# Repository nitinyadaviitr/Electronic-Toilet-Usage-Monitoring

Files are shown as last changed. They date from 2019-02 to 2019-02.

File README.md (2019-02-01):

# Electronic-Toilet-Usage-Monitoring
For accelerating the effectiveness of Swachh Bharat Abhiyaan, the monitoring of the goals under Swachh Bharat Abhiyaan is the most important thing to be done.
To successfully implement the cause of the Millions of toilets made under Swachh Bharat Abhiyaan, having a record of how much they are actually being used is important.
For monitoring toilet usage in the rural areas of India, we have developed ETUM. 
ETUM has been made considering conditions like lack of electricity in villages, remoteness of the area and lack of services.
ETUM is a cost effective device which will tell the approximate usage of the toilets for a duration of about 5 months after which the data will have to be recorded manually.

General Description:-
ETUM operates on the principle of human detection technology using a PIR sensor. A PIR sensor detects Infrared rays emitted by the human body.
Everytime a person enters into the toilet, the PIR sensor will read high increasing the previous value by 1, and will store this data for about 5 months with average usage in every week during these
months.
Our idea suggests that the device will be installed in every toilet present into the village and after a duration of 5 months a person has to go to every house and take
the reading of the device and replace the battery used in it. Then he will give the feedback to a centralised database where the data of all the villages will be recorded and studied.
The device is accurate as whole device works without manual work (except manual recording) and has a long lifetime if not damaged physically.

Cost-effectiveness:-
Calculating the whole manufacturing of the device along with the price of each and every component used in it, the device will have an estimated cost of 150 rupees.
The exact cost of the device depends on the amount of quantities being ordered collectively and from where they are being ordered and many other factors.
(The price data of products we have considered for evaluation of cost of our device have been provided in the PDF attached)

Scalability:-
The device is safe to use and have an optimum cost for a large scale usage in rural or urban areas.
The device has no maintenance cost and low operating cost.
Also assigning the responsibility of data recording from every house in the village to a person is feasible and would help to keep an accurate record of the whole data.
Extremely low maintenance cost, long lifetime and low cost of the device makes it perfect for large scale usage.

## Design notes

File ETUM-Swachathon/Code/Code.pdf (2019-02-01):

/*
* main.c
*
* Created on: 25-Aug-2017
* Author: utkarsh
*/

#define F_CPU 8000000UL

#define LCD_PRT PORTA

#define LCD_DDR DDRA

#define LCD_PIN PINA

#define LCD_RS 3

#define LCD_EN 2

#define LCD_RW 1

#include <avr/io.h>

#include <util/delay.h>

#include <stdlib.h>

#include <avr/interrupt.h>

volatile unsigned int counter=0; | //Counter for Timer/Counter1
int day=0; | //Number of days passed
unsigned int month[6]; | //Array of monthly usage data
char month_no=0;
int count=0; | //PIR Count of people

void delay_us(int d)
{
_delay_us(d)
}

void delay_ms(int d)
{
_delay_ms(d)
}

// Functions of Timer/Counter1
ISR(TIM1_OVF) | //Timer/Counter1 Overflow ISR
{
counter++; | //+2 sec
TCNT1H=0xC2; | // Adding offset
TCNT1L=0xF5;
}
void initT1() | //Initialization of Timer/Counter1
{
TCNT1H=0xC2; | // Adding offset
TCNT1L=0xF5;
TCCR1A=0x00; | //Normal Mode
TCCR1B=0x05; | //prescaler of 1024

TIMSK1 |= 1<<TOIE1; | //enable Timer/Counter1 overflow interrupt
}

//Function of Pir Sensor
ISR(INT0)
{
count++;
GIMSK = 0x00; | //Disable External Interrupt Request
delay_ms(120000); | //Delay of 2 min
GIMSK =(1<<INT0)|(0<<PCIE1)|(0<<PCIE0); | //External Interrupt Request 0
//Enable and Pin Change Interrupt //Disable for 1 and 0
}
void initI0() | //Initialization Of External Interrupt 0
{
GIMSK =(1<<INT0)|(0<<PCIE1)|(0<<PCIE0); | //External Interrupt Request 0
//Enable and Pin Change Interrupt //Disable for 1 and 0
MCUCR = (1<<ISC01)|(1<<ISC00); | //The rising edge of INT0 generates
//an interrupt request
}

//LCD
void lcdCommand( unsigned char cmnd )
{
LCD_PRT = (LCD_PRT & 0x0F) | (cmnd & 0xF0);
LCD_PRT &= ~ (1<<LCD_RS); | //RS = 0 for command
LCD_PRT &= ~ (1<<LCD_RW); | //RW = 0 for write
LCD_PRT |= (1<<LCD_EN); | //EN = 1 for H-to-L pulse
delay_us(1); | //make EN pulse wider
LCD_PRT &= ~ (1<<LCD_EN); | //EN = 0 for H-to-L pulse
delay_us(20); | //wait
LCD_PRT = (LCD_PRT & 0x0F)|(cmnd<<4); | //Send low nibble to D4-D7
LCD_PRT |= (1<<LCD_EN); | //EN = 1 for H-to-L pulse
delay_us(1); | //make EN pulse wider
LCD_PRT &= ~ (1<<LCD_EN); | //EN = 0 for H-to-L pulse
}

void lcdData( unsigned char data )
{
LCD_PRT = (LCD_PRT & 0x0F) | (data & 0xF0); | //Send high nibble to D4-D7
LCD_PRT |= (1<<LCD_RS); | //RS = 1 for data
LCD_PRT &= ~ (1<<LCD_RW); | //RW = 0 for write
LCD_PRT |= (1<<LCD_EN); | //EN = 1 for H-to-L pulse
delay_us(1); | //make EN pulse wider
LCD_PRT &= ~ (1<<LCD_EN); | //EN = 0 for H-to-L pulse
LCD_PRT = (LCD_PRT & 0x0F) | (data <<4); | //Send low nibble to D4-D7

LCD_PRT |= (1<<LCD_EN); | //EN = 1 for H-to-L pulse
delay_us(1); | //make EN pulse wider
LCD_PRT &= ~ (1<<LCD_EN); | //EN = 0 for H-to-L pulse
}

void lcd_init()
{
LCD_DDR = 0x7F;
LCD_PRT &=~(1<<LCD_EN); | //LCD_EN = 0
delay_us(2000);
lcdCommand(0x33); | //send $33 for init.
delay_us(100);
lcdCommand(0x32); | //send $32 for init
delay_us(100);
lcdCommand(0x28); | //init. LCD 2 line,5*7 matrix
delay_us(100);
lcdCommand(0x0e); | //display on, cursor on
delay_us(100);
lcdCommand(0x01); | //clear LCD
delay_us(2000);
lcdCommand(0x06); | //Shift cursor right
delay_us(100);
}
void lcd_gotoxy(unsigned char x, unsigned char y) | //function to goto x,y on LCD
{
unsigned char firstCharAdr[]={0x80,0xC0,0x94,0xD4} ; lcdCommand(firstCharAdr[y-1] + x - 1);
delay_us(100);
}
void lcd_print(char * str ) | //function to print given str. on LCD
{
unsigned char i = 0 ;
while(str[i]!=0)
{
lcdData(str[i]);
i++ ;
}
}

//Main Code
int main(void)
{
DDRA=0b00111111; | //LCD Interfacing
PORTB2=1; | //pull up activated
initI0(); | //External Interrupt 0
initT1(); | //Timer/Counter1 to count time

sei(); | //enable global interrupt
while(1)
{
if(counter>=43200) | //No of days passed (30*60*24 = 43200 )
{
day++; | //+day
counter=counter-43200; | //counter remainder
}
if (day==30)
{
month[month_no]=((count/2)/30); | //Assigning monthly average data
month_no++; | //+month_no
day=0;
}
}

if ( PINA & 0b00000001)
{
//LCD code
lcd_init();
lcd_gotoxy(1,1);
lcd_print(“%4d %4d %4d”,month[0], month[1], month[2]); lcd_gotoxy(1,2);
lcd_print(“%4d %4d %4d”,month[3], month[4], month[5]);

}

}

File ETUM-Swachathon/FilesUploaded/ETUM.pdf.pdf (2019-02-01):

# ETUM

ELECTRONIC TOILET USAGE MONITORING

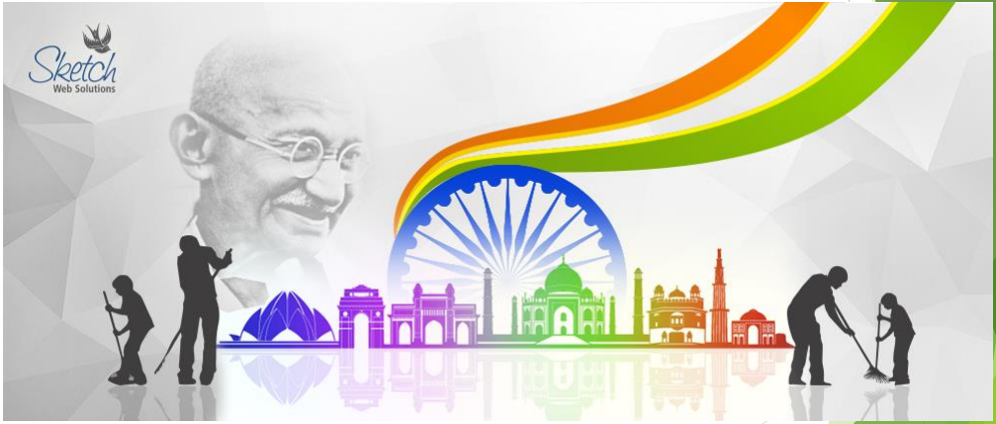
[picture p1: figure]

# ETUM

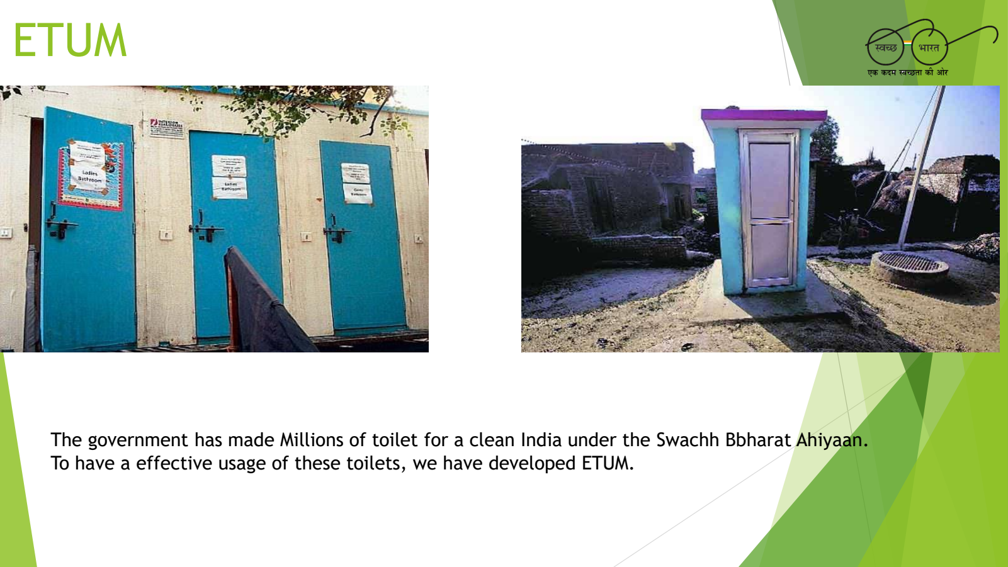
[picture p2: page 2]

The government has made Millions of toilet for a clean India under the Swachh Bbharat Ahiyaan. To have a effective usage of these toilets, we have developed ETUM.

# ETUM WORKING`

# ETUM

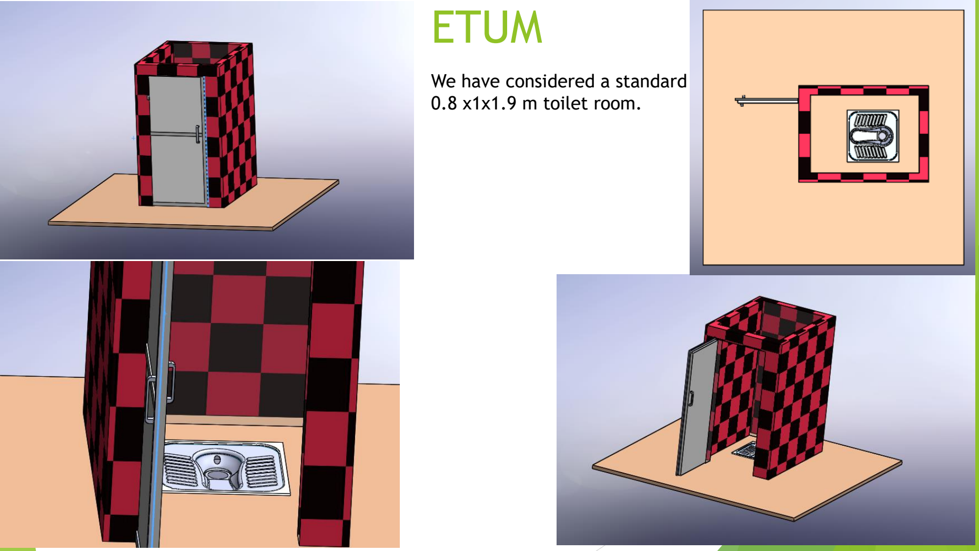
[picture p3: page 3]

We have considered a standard 0.8 x1x1.9 m toilet room.

# PIR SENSOR

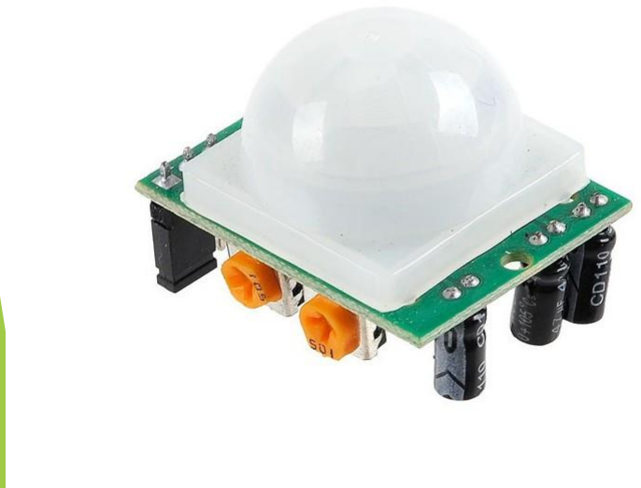
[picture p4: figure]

PIR sensors allow you to sense motion, almost always used to detect whether a human has moved in or out of the sensors range. They are small, inexpensive, lowpower, easy to use and don't wear out. For that reason they are commonly found in appliances and gadgets used in homes or businesses. They are often referred to as PIR, "Passive Infrared", "Pyroelectric", or "IR motion" sensors.

# ETUM

# PIR SENSOR

PIRs are basically made of a pyroelectric sensor (which you can see above as the round (http://en.wikipedia.org/wiki/Pyroelectric) metal can with a rectangular crystal in the center), which can detect levels of infrared radiation. Everything emits some low level radiation, and the hotter something is, the more radiation is emitted. The sensor in a motion detector is actually split in two halves. The reason for that is that we are looking to detect motion (change) not average IR levels. The two halves are wired up so that they cancel each other out. If one half sees more or less IR radiation than the other, the output will swing high or low.

# ETUM

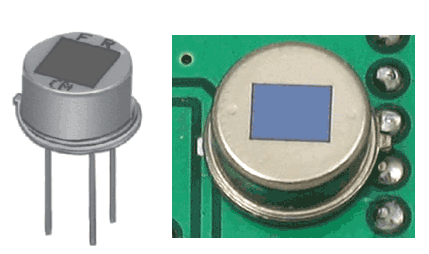
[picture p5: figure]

# PIR SENSOR WORKING

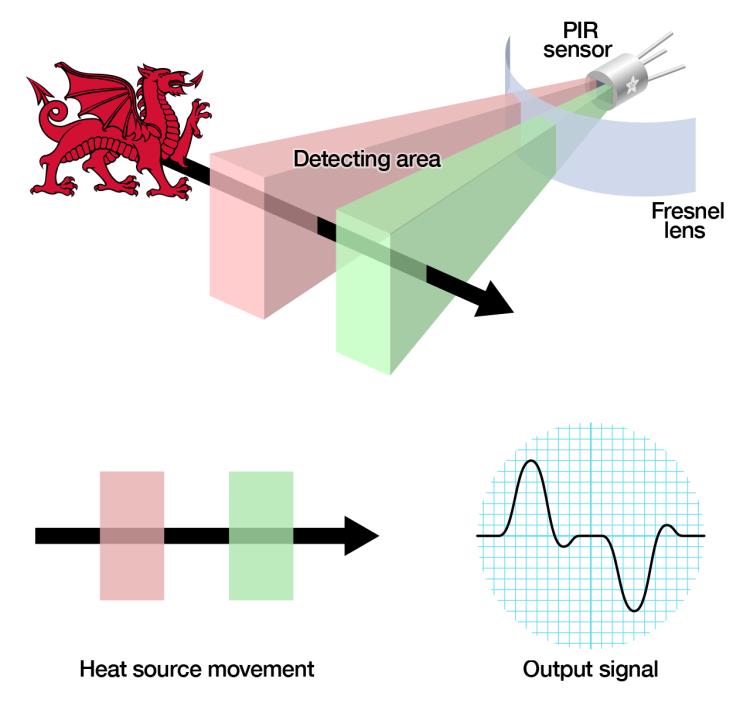
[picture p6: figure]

The PIR sensor itself has two slots in it, each slot is made of a special material that is sensitive to IR. When the sensor is idle, both slots detect the same amount of IR, the ambient amount radiated from the room or walls or outdoors. When a warm body like a human or animal passes by, it first intercepts one half of the PIR sensor, which causes a positive differential change between the two halves. When the warm body leaves the sensing area, the reverse happens, whereby the sensor generates a negative differential change. These change pulses are what is detected.

# ETUM

# ETUM WORKING

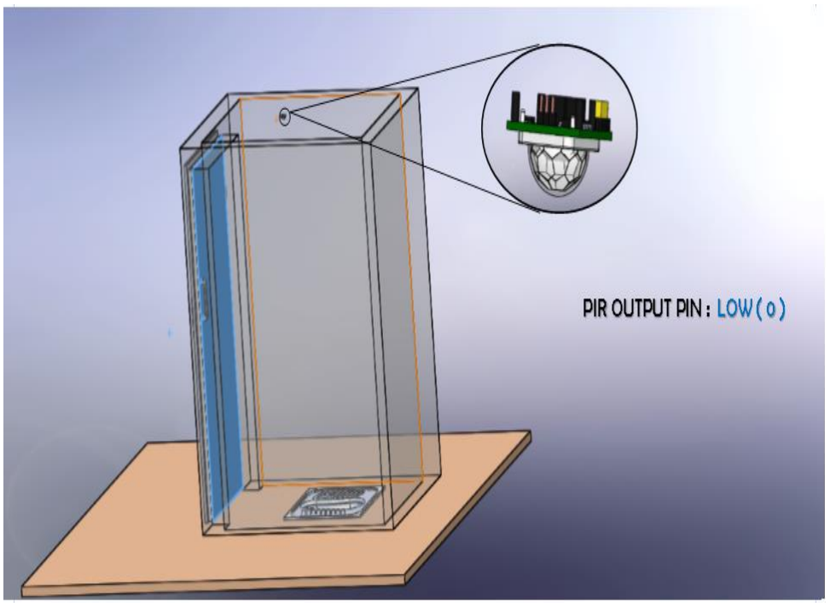
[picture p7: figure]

When the toilet is not being used, the sensor reads low.

# ETUM WORKING

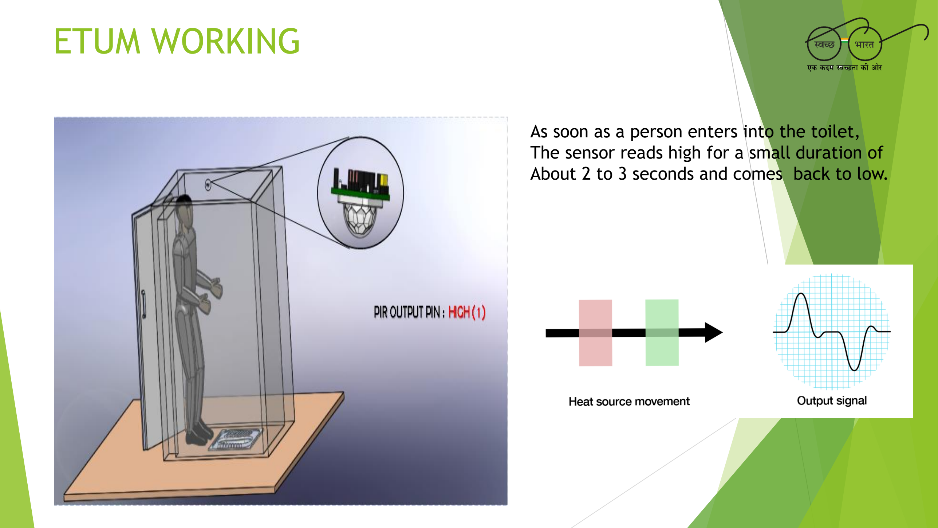
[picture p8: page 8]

As soon as a person enters into the toilet, The sensor reads high for a small duration of About 2 to 3 seconds and comes back to low.

# ETUM IDEA

The device works on the principle of infrared rays detection by a PIR sensor. The device is designed to work continuously for about 5 months without any maintenance in between.
After duration of these 5 months, a person will have to record the data that Is stored in these 5 months by plugging in an LCD screen into the LCD pins Provided in ETUM.

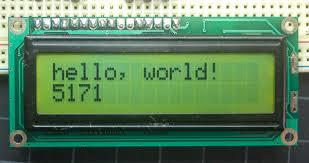
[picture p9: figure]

A Standard 16x2 LCD screen.

# ETUM IDEA

We instead of using a standard HC-SR501, have designed our own PCB module removing the unnecessary voltage Regulator and potentiometer for minimum power dissipation. We in the PCB we have added a microcontroller(ATTINY 24A) for the processing of the data along with separate pins in which the LCD has to be Plugged-in to read the data. A battery of 3000mAh is used in the device.
Here is a list of the components used in the device:-

Resistor(ohms)
47k -1
6.8k -1
2k -1
10k -5
18k -3
470k -1
1M -3
1k -1

Capacitor
5nF -1
47uF -1
22uF -2
100nF -2
10nF -5

ICs and PIR
ATTINY 24A
BISS0001 SMD
RE200B

3000mAh
Rechargeable battery 1

# ETUM PCB SCHEMATIC

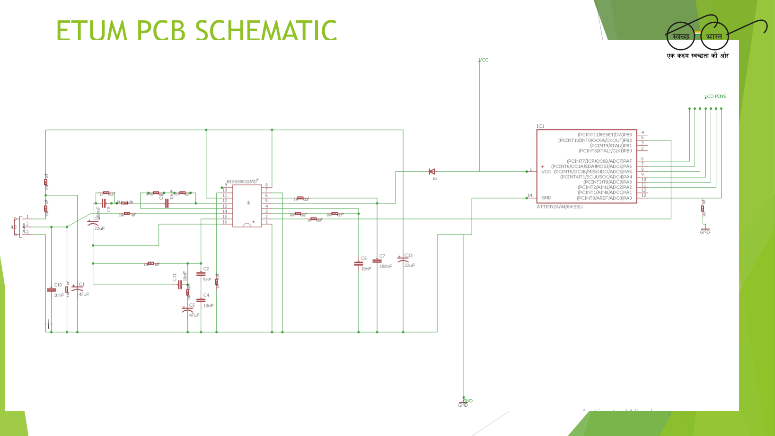
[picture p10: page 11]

# ETUM PCB BOARD

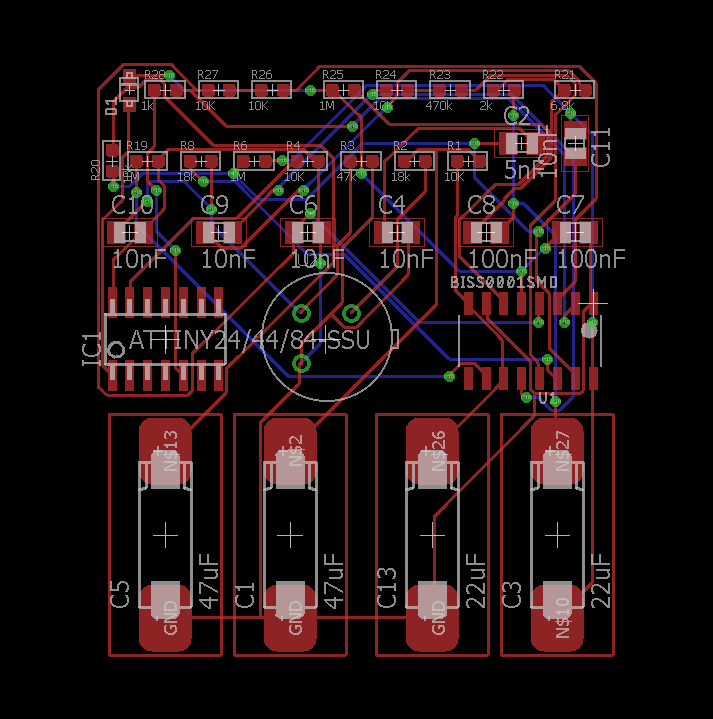
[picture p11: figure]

## PCB design of ETUM

# ETUM PCB BOARD

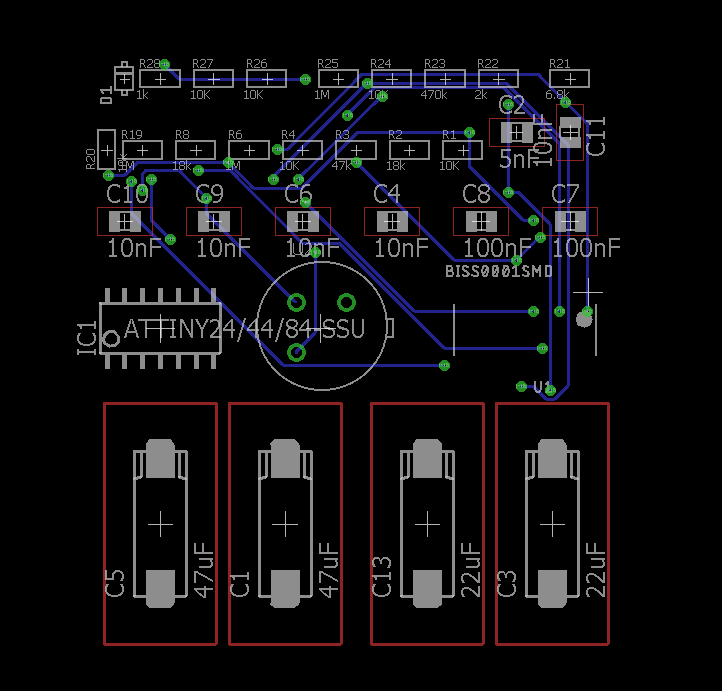
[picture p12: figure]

Bottom layer of PCB.

# ETUM PCB BOARD

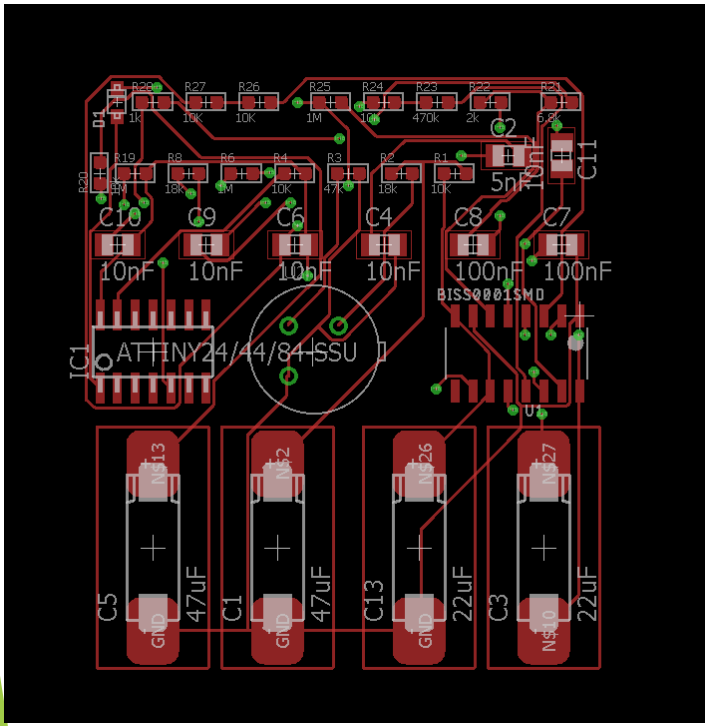
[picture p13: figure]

# Top layer of PCB

COST in ETUM manufacturing.

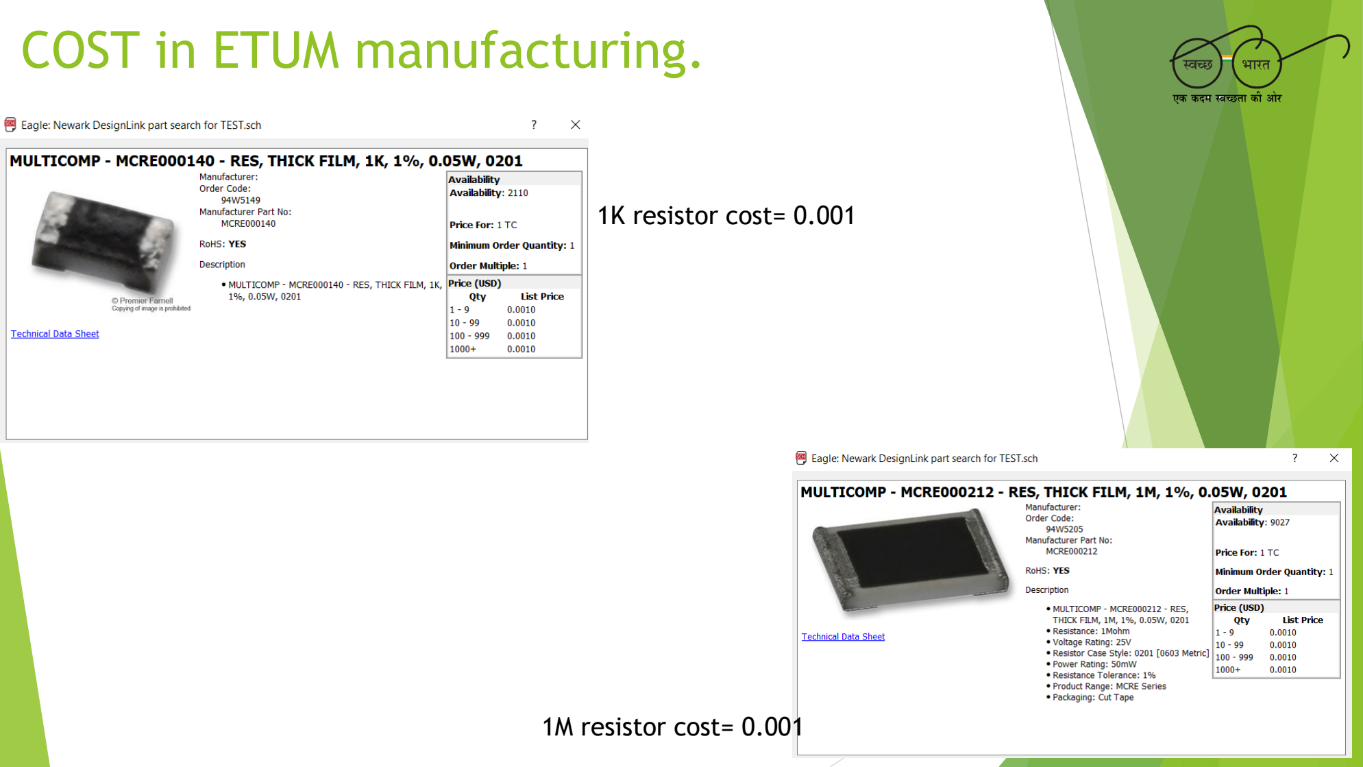
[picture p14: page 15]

1K resistor cost= 0.001

1M resistor cost= 0.001

COST in ETUM manufacturing.

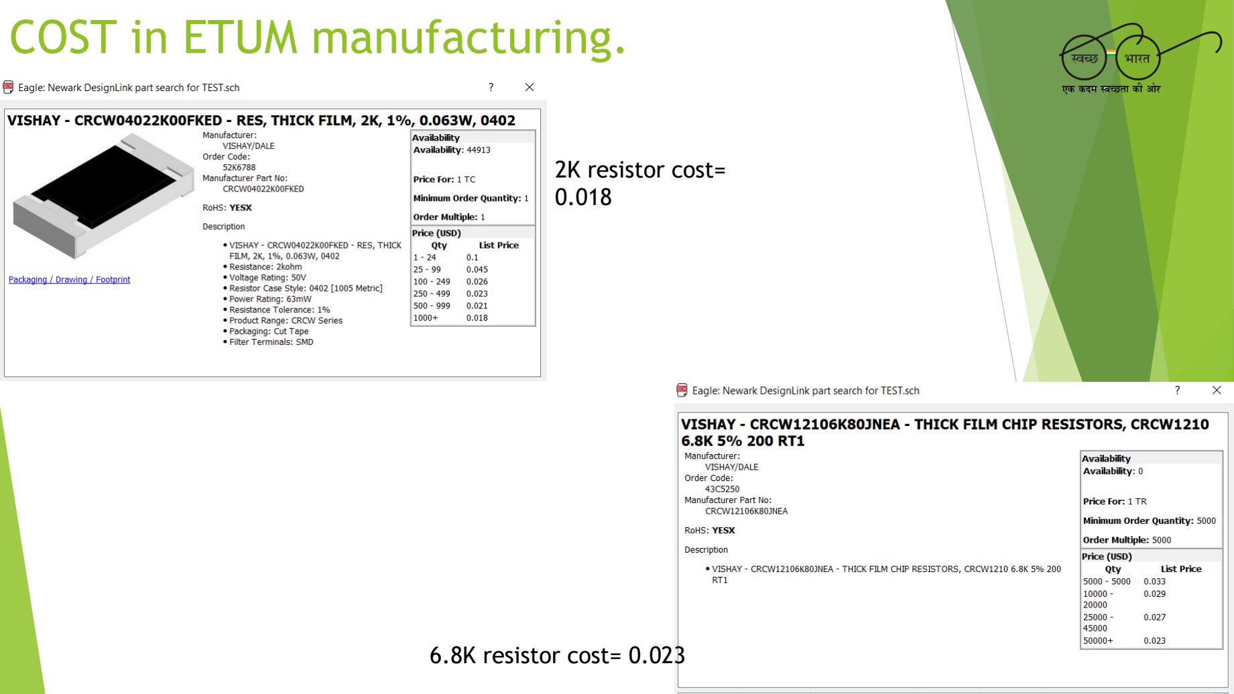
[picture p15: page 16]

2K resistor cost=
0.018

6.8K resistor cost= 0.023

COST in ETUM manufacturing.

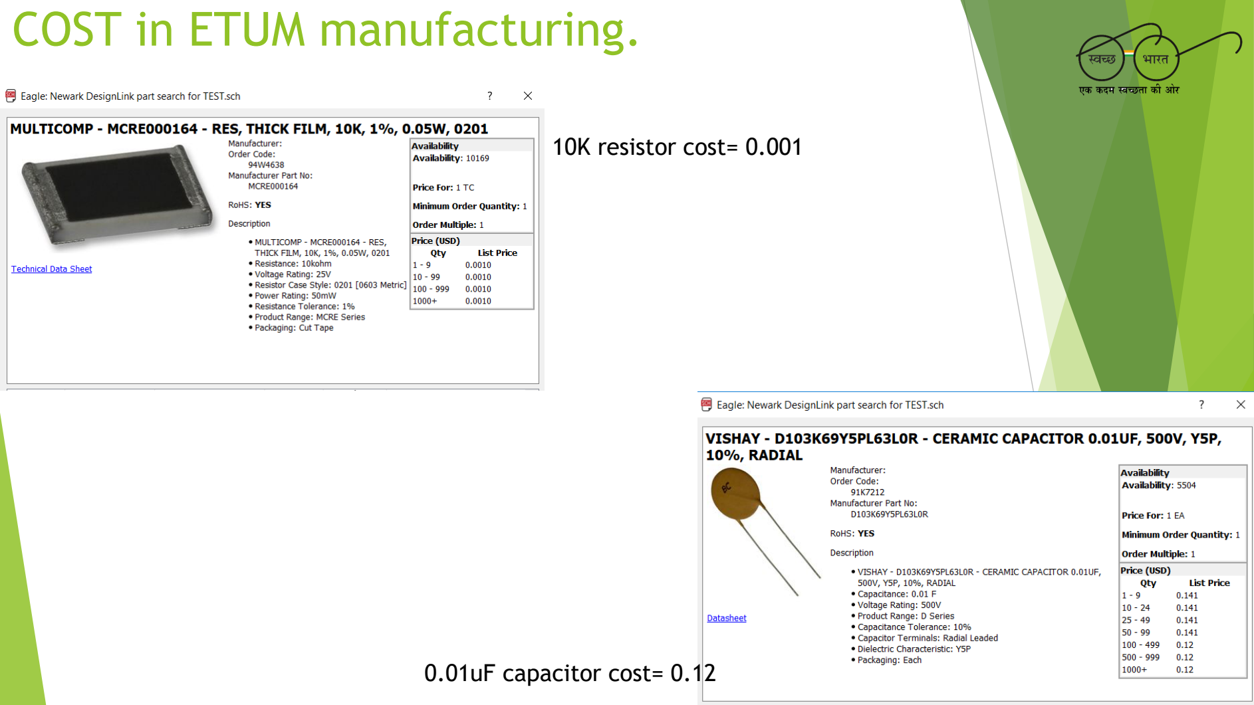
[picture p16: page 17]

10K resistor cost= 0.001

0.01uF capacitor cost= 0.12

COST in ETUM manufacturing.

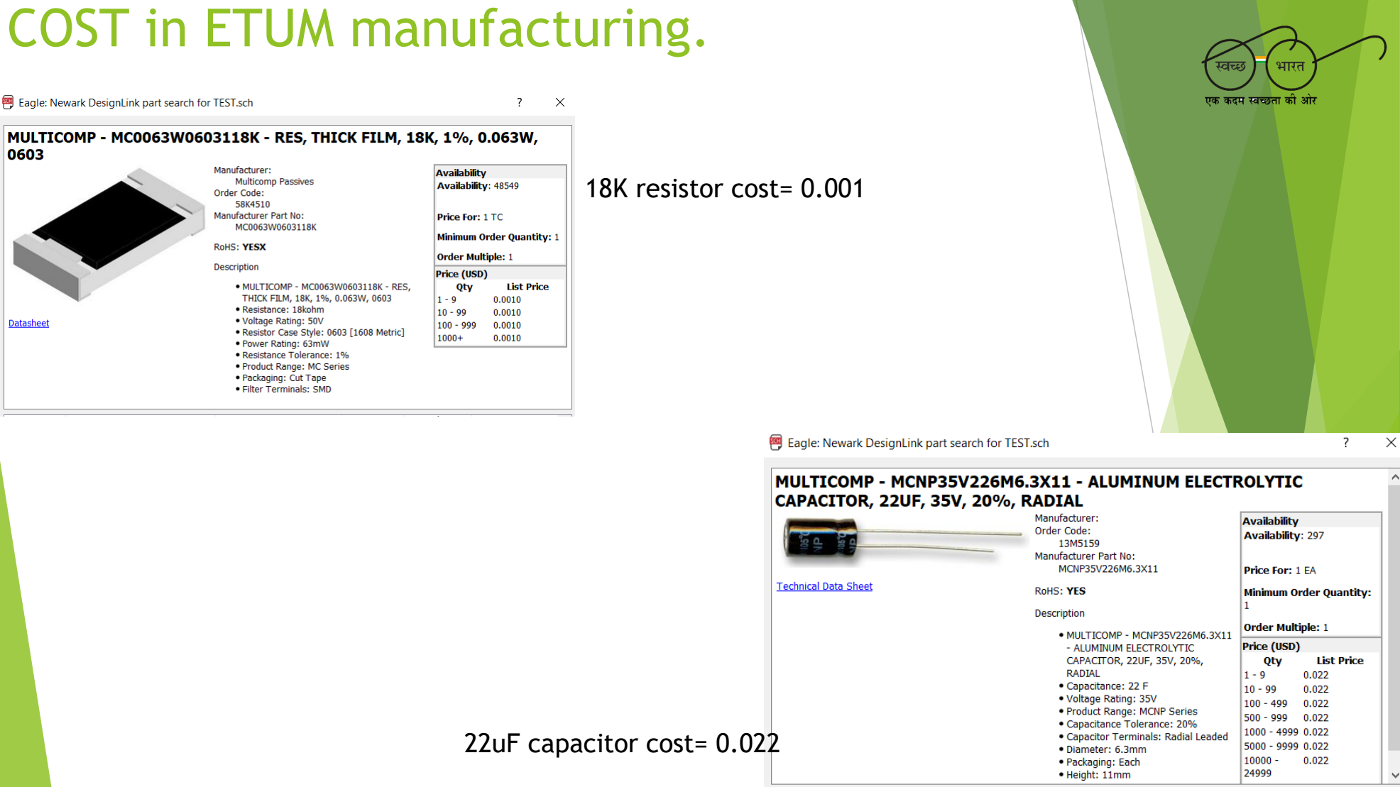
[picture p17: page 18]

18K resistor cost= 0.001

22uF capacitor cost= 0.022

COST in ETUM manufacturing.

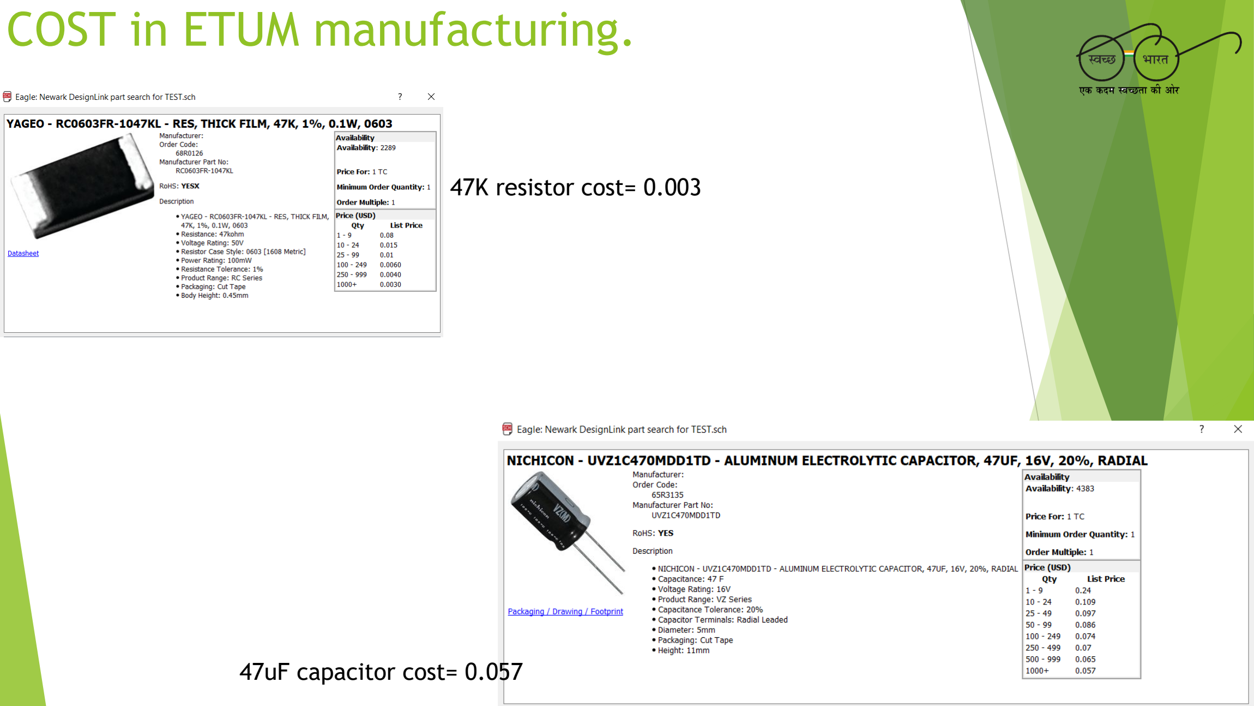
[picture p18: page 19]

47K resistor cost= 0.003

47uF capacitor cost= 0.057

COST in ETUM manufacturing.

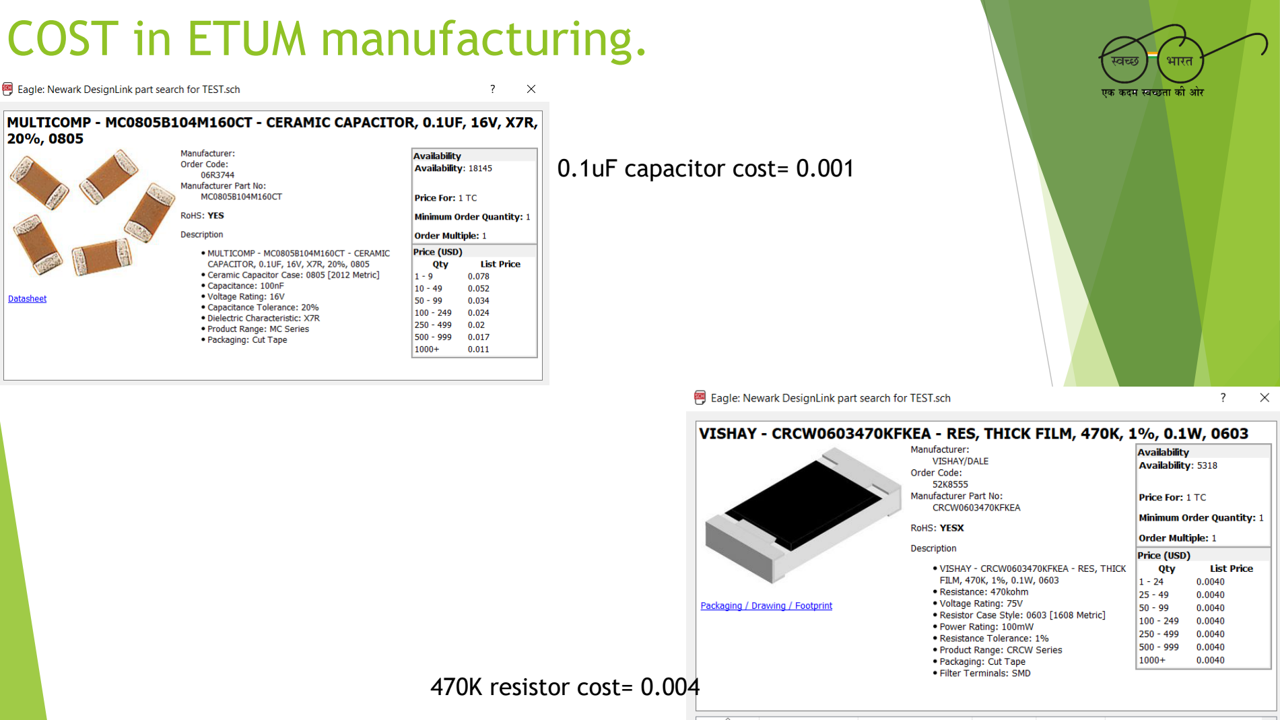
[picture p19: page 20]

0.1uF capacitor cost= 0.001

470K resistor cost= 0.004

COST in ETUM manufacturing.

The link to the website we have referred to buy all these products mentioned above is given below:-www.newark.com

BISS0001 reference link to buy is:-"https://www.aliexpress.com/item/BISS0001-smd-sop16-1000pcs-lot-sensorsinfrared-sensor-ic-Infrared-sensor-signal-processor-We-canoffer/32624873306.html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"
ATTINY 24A(SSU) reference link to buy is:-"https://l.facebook.com/l.php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 TcDcn-Xq5z2nCcVwqAmaUceGNCP1VwTRRyCmDyiaobLr_Lu3gfhr_9g98PFVk_CxLnTwbSWmDfCHd6nc3a oxv1tuG0jaGUyg"
PIR sensor:-
"https://www.alibaba.com/product-detail/types-of-pir-sensor-pirsensor_60528709780.html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"

3000mAh Battery:-
"https://www.alibaba.com/product-detail/Full-Capacityoriginal-lg-hg2-
3000mah_60503919326.html?spm=a2700.7724857.main07.2 07.2bd13975hQXAYq"

# ETUM

# How far we have reached?

ETUM is designed to detect human presence in a range of about 1m.
For toilet usage monitoring, it is an optimum amount of distance to be measured.
The battery life of the device is about 5 months. To minimize the operating cost,
We have used a 2400mAh battery, but if we want to increase the battery life of the device, A higher mAh battery can be used (which will increase the cost).
For toilet usage monitoring, ETUM is a perfect device as 5 months is enough to determine how much the toilet is being used regularly and the future predictions can be made easily.

# ETUM

# Future plans

Under proper guidance and with the help of the best minds of India, we have a goal to install ETUM in each and every Indian house. Swachh Bharat Abhiyaan, an initiative by Respectful PM Narendra Modi, has to be taken seriously for a clean and beautiful India. And using the best minds of the country in this is the need of the hour.

We have a goal to make ETUM more efficient, accurate and cost-efficient. We will work further to increase The battery life and durability of the device and make it optimum for monitoring toilet usage.

# ETUM

- Link to the SolidWorks file, PCB design, ATtiny24A Code and other data is
given below:-

https://drive.google.com/drive/folders/0B7fBHyx3akR_MkswR0VGWkpjUFk?usp=sharing

# TEAM MEMBERS

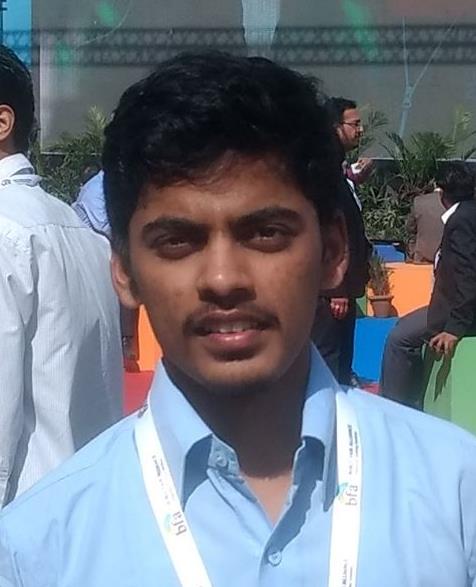
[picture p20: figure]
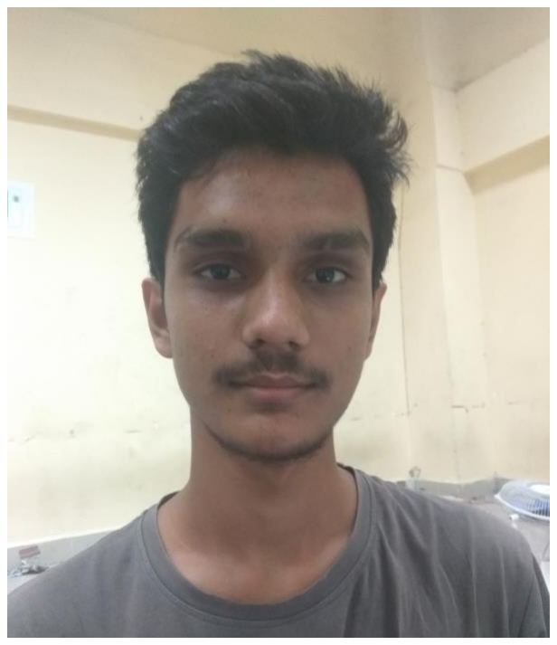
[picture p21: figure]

Utkarsh Deepak | Nitin Yadav
utkarsh230897@gmail.com | yadav.nitin558@gmail.com
Electronics, ATtiny24A code | Electronics,PCB

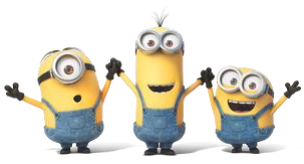
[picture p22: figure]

# THANK YOU!

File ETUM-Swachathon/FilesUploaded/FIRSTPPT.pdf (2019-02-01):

# ETUM

An initiative for effective implementation of Swachh Bharat Abhiyaan.

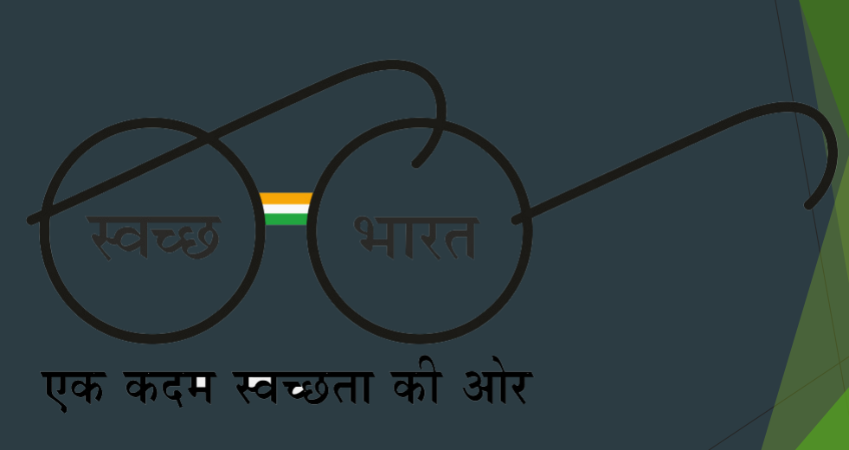
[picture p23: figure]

# ETUM

1. The estimated cost of the device is 150 rupees, no maintenance cost is required as we have used a rechargeable battery.

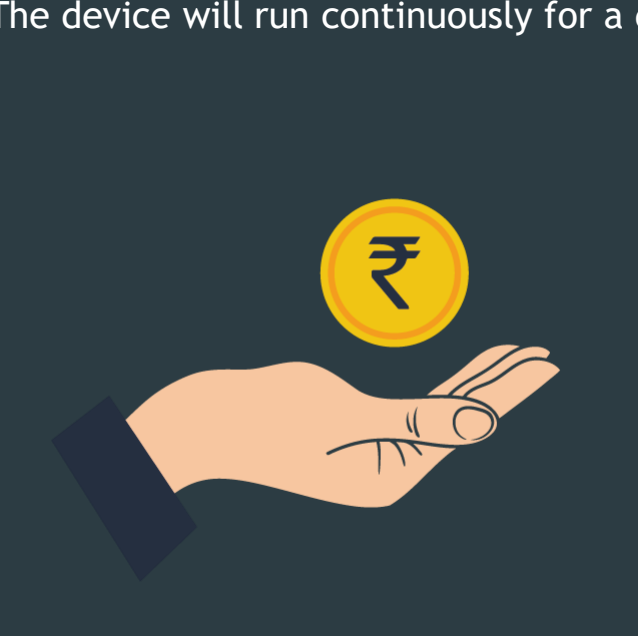
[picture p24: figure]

2.The device will run continuously for a duration of about 5-6 months.


# ETUM

The device is designed to work even if there is no regular supply of electricity in the area.


# ETUM

A person will record the data from the device after a period of 5-6 months.


# ETUM

The low cost, long lifetime and no maintenance cost makes it optimum for large scale usage.


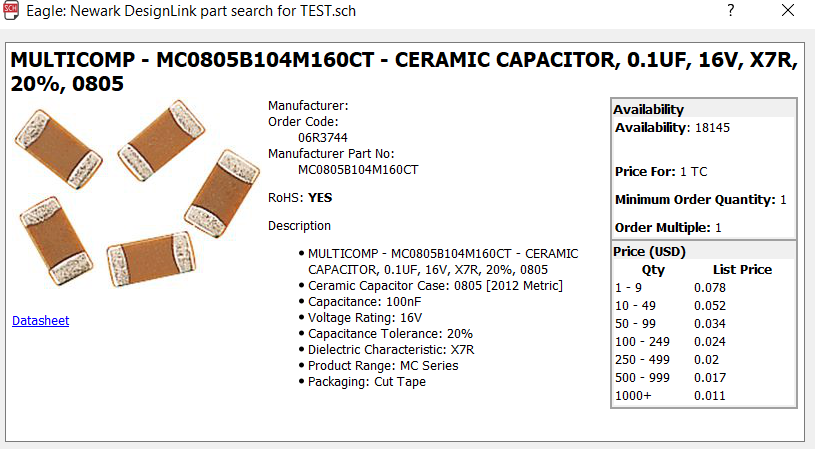
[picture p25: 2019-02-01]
ETUM-Swachathon/Price/100nF.PNG

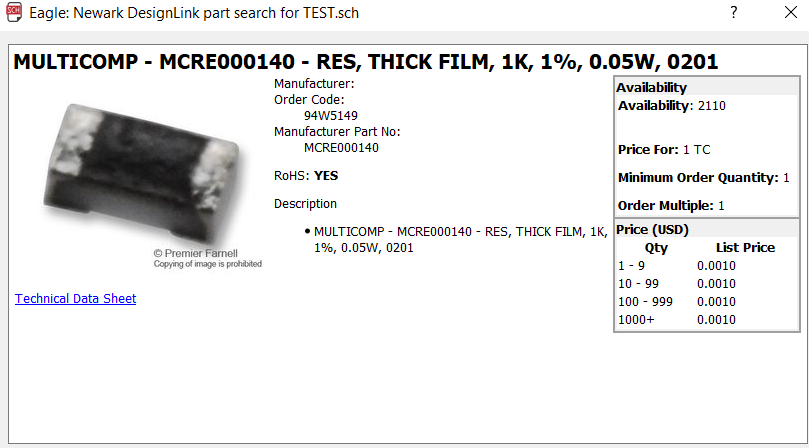
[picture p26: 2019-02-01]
ETUM-Swachathon/Price/1kohm.PNG

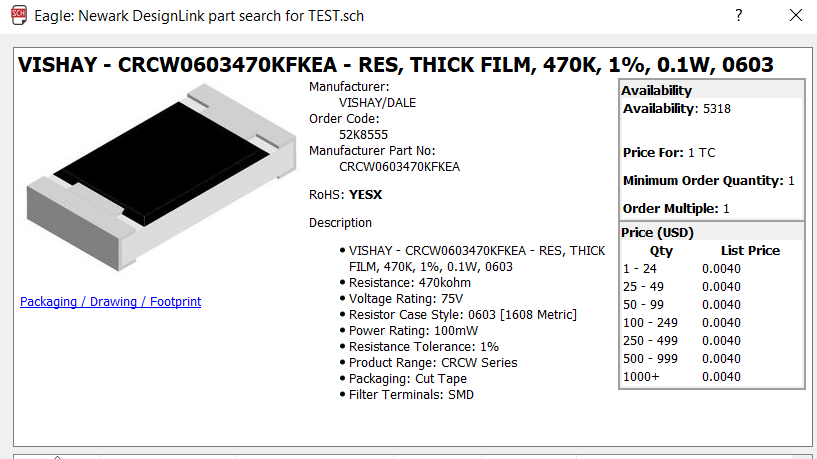
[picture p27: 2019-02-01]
ETUM-Swachathon/Price/470kohm.PNG

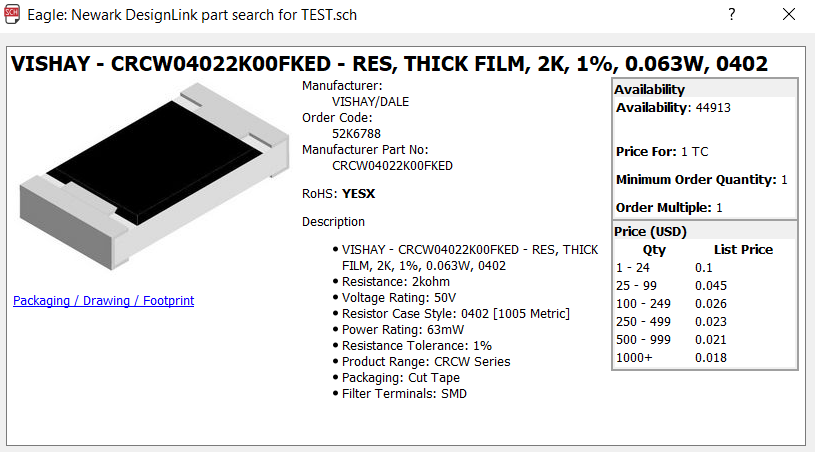
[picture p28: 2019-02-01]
ETUM-Swachathon/Price/2kohm.PNG

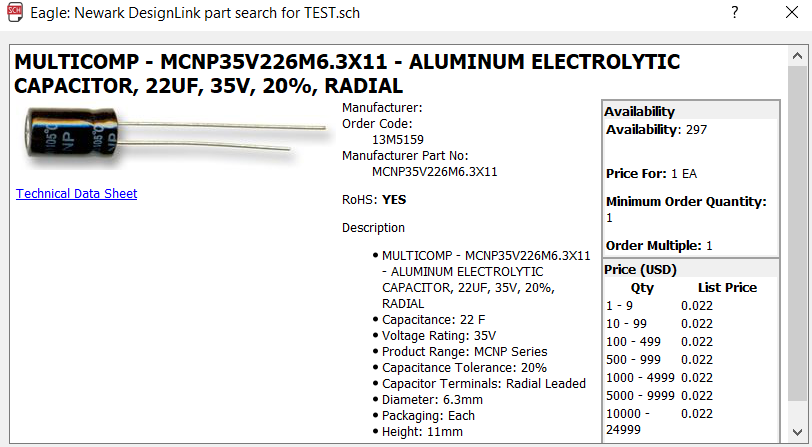
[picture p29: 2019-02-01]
ETUM-Swachathon/Price/22uF.PNG

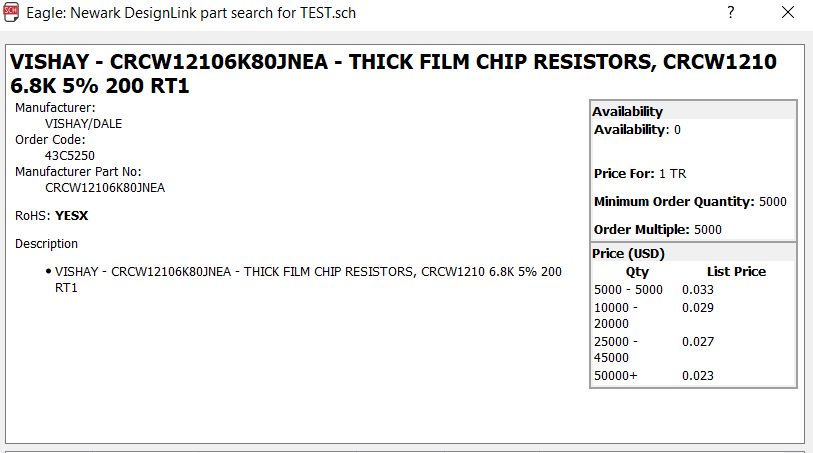
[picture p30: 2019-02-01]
ETUM-Swachathon/Price/6.8kohm.PNG

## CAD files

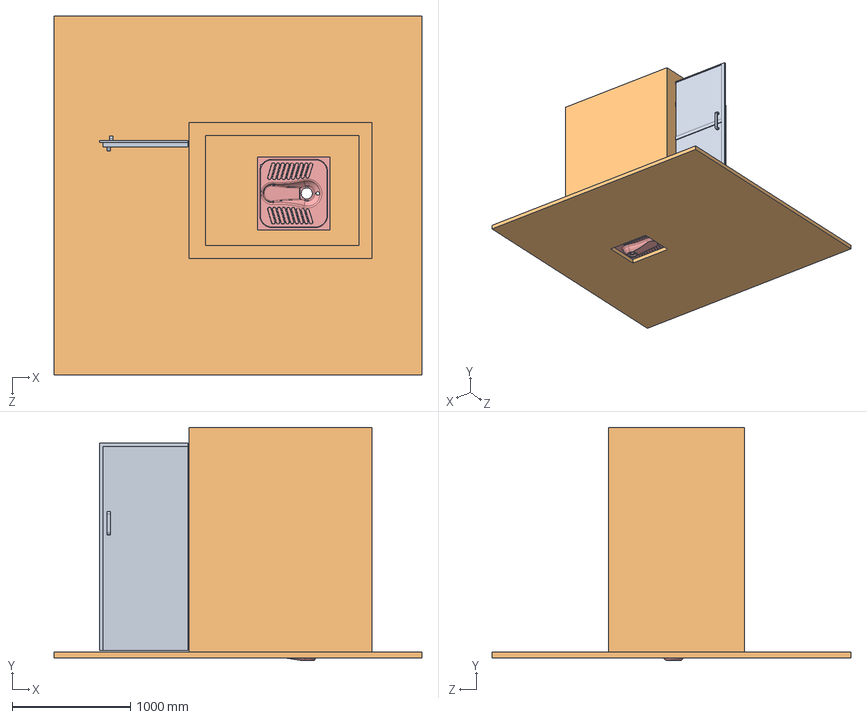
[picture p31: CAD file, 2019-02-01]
ETUM-Swachathon/SolidWorks/Main Assembly.SLDASM
3107.9 x 1970.0 x 3035.1 mm
gate
wall
HingeP1
HingeP2
toilet seat

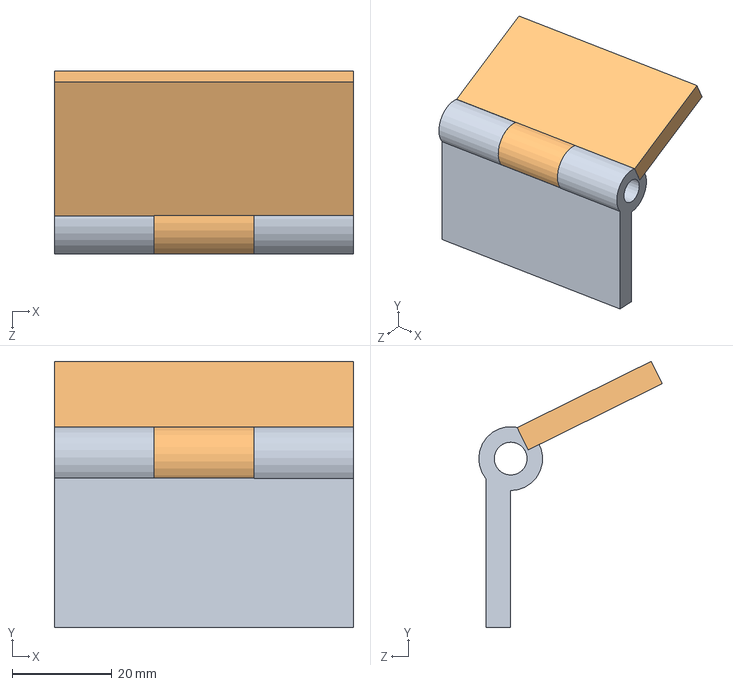
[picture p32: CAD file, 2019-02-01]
ETUM-Swachathon/SolidWorks/HINGE.SLDASM
60.0 x 53.4 x 36.8 mm
hi
hi1

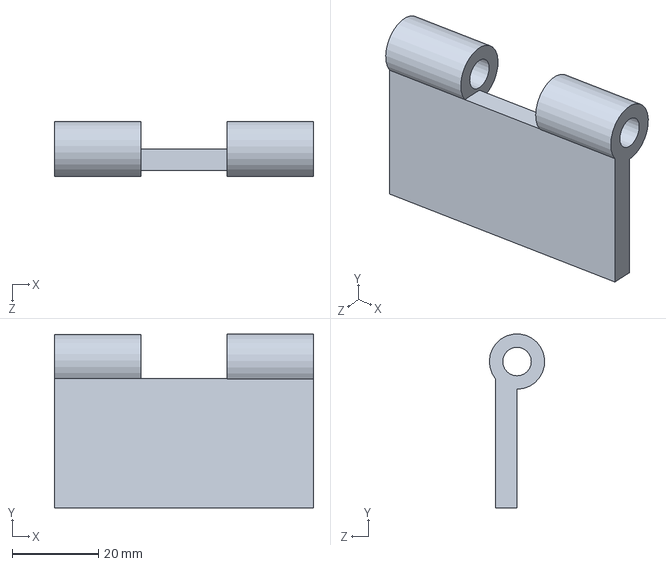
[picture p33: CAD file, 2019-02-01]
ETUM-Swachathon/SolidWorks/HingeP1.SLDPRT
60.0 x 40.3 x 12.8 mm

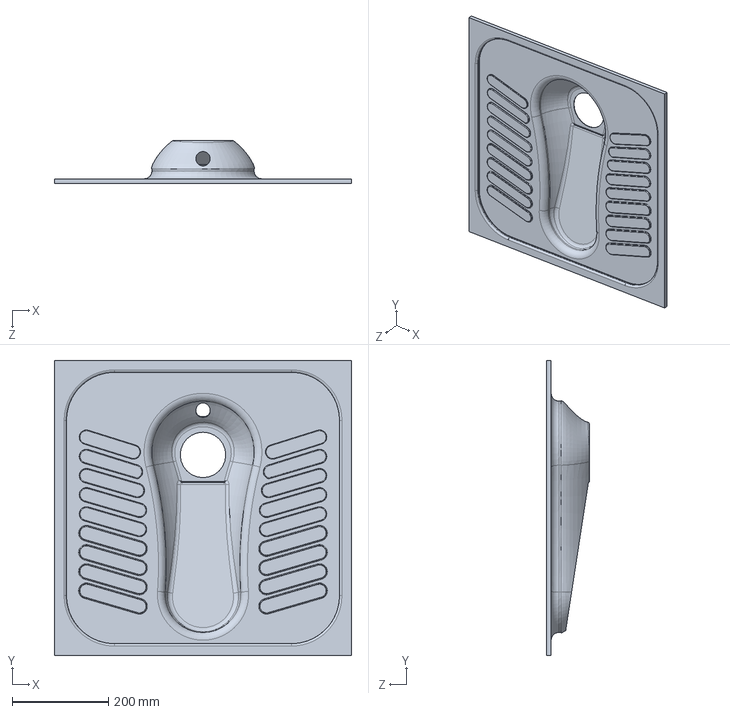
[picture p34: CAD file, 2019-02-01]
ETUM-Swachathon/SolidWorks/Toilet Seat.SLDPRT
618.7 x 615.2 x 90.0 mm

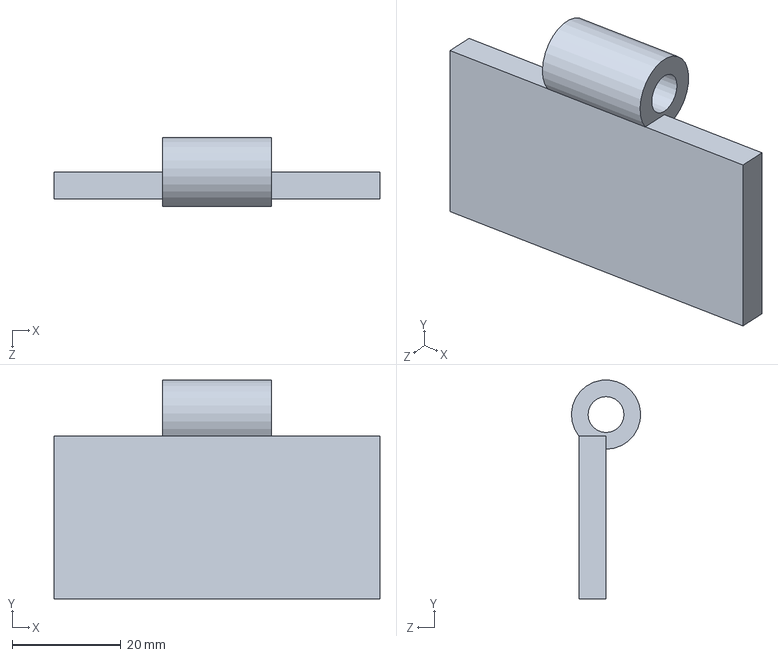
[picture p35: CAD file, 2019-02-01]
ETUM-Swachathon/SolidWorks/HingeP2.SLDPRT
60.0 x 40.3 x 12.7 mm

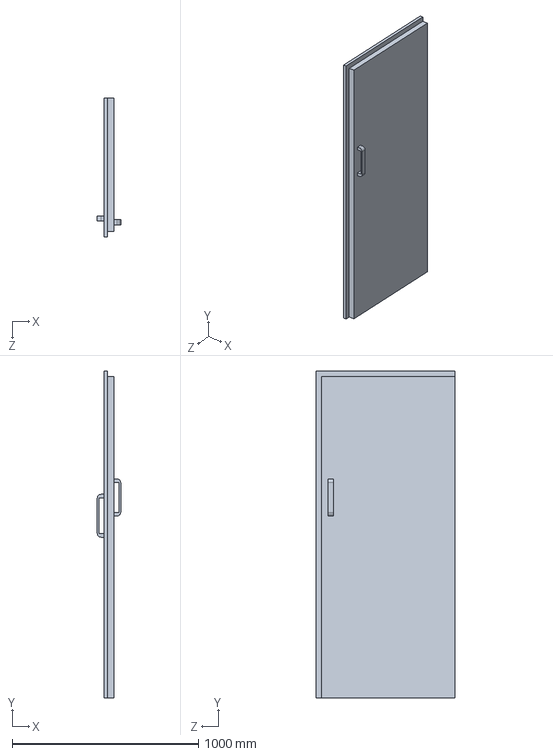
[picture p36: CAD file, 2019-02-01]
ETUM-Swachathon/SolidWorks/Gate.SLDPRT
126.2 x 1755.0 x 747.5 mm

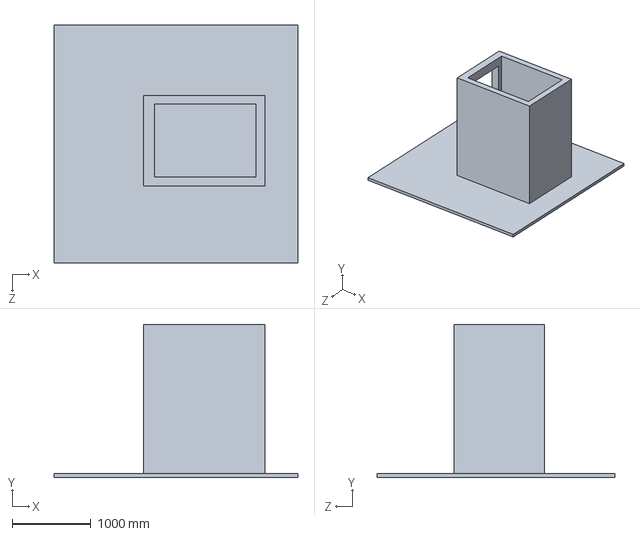
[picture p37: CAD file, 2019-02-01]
ETUM-Swachathon/SolidWorks/Wall.SLDPRT
3107.9 x 1950.0 x 3035.1 mm

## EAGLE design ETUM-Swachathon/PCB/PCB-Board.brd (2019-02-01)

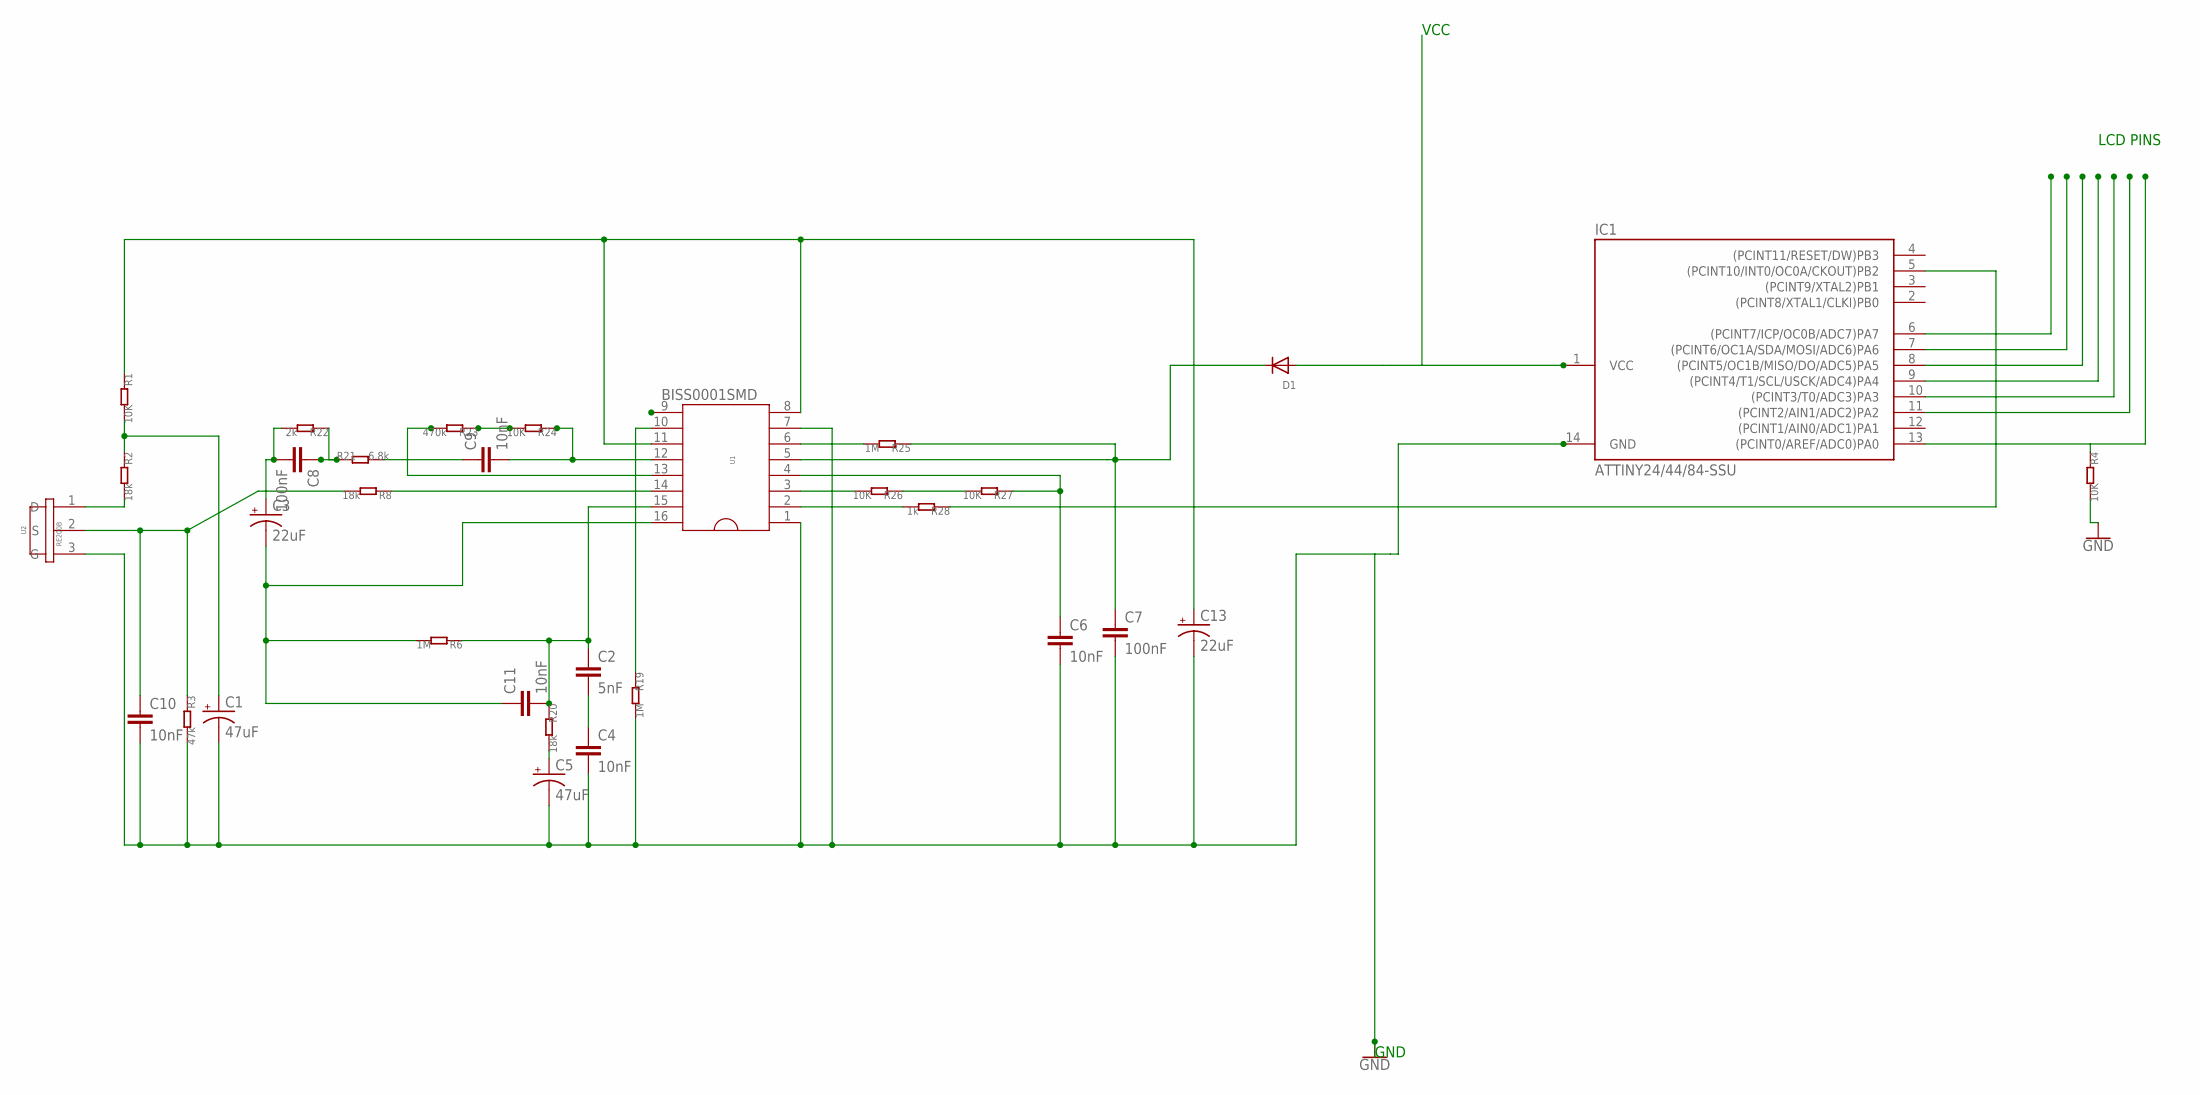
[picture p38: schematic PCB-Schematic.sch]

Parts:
C1, C5: 47uF; 085CS_1W
C2: 5nF; C0805
C3, C13: 22uF; 085CS_1W
C4, C6, C9, C10, C11: 10nF; C0805
C7, C8: 100nF; C0805
D1: DIODESOD-323F; SOD-323F
IC1: ATTINY24/44/84-SSU; SOIC14
R1, R4, R24, R26, R27: 10K; R0603
R2, R8, R20: 18k; R0603
R3: 47k; R0603
R6, R19, R25: 1M; R0603
R21: 6.8k; R0603
R22: 2k; R0603
R23: 470k; R0603
R28: 1k; R0603
U1: BISS0001SMD; SOP16
U2: RE200B

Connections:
GND: C1.-, C4.2, C5.-, C6.2, C7.2, C10.2, C13.-, IC1.14 (GND), R3.2, R4.2, R19.2, U1.1, U1.7, U2.3 (G)
unnamed: R2.2, U2.1 (D)
unnamed: C1.+, R1.2, R2.1
unnamed: R19.1, U1.10
unnamed: R23.2, U1.13
unnamed: R8.1, U1.14
unnamed: C10.1, R3.1, R8.2, U2.2 (S)
unnamed: C3.-, C11.1, R6.2, U1.16
unnamed: C8.1, R21.1, R22.1
unnamed: C9.1, R21.2
unnamed: C5.+, R20.2
unnamed: C2.1, C11.2, R6.1, R20.1, U1.15
unnamed: C2.2, C4.1
unnamed: R25.2, U1.6
unnamed: R23.1, R24.2
unnamed: C6.1, R27.1, U1.4
unnamed: R26.2, U1.3
unnamed: C7.1, D1.C, R25.1, U1.5
unnamed: C9.2, R24.1, U1.12
unnamed: R28.2, U1.2
unnamed: R26.1, R27.2
unnamed: IC1.5 ((PCINT10/INT0/OC0A/CKOUT)PB2), R28.1
unnamed: C13.+, R1.1, U1.8, U1.11
unnamed: C3.+, C8.2, R22.2
unnamed: D1.A, IC1.1 (VCC)
unnamed: IC1.13 ((PCINT0/AREF/ADC0)PA0), R4.1

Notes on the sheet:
VCC
GND
LCD PINS

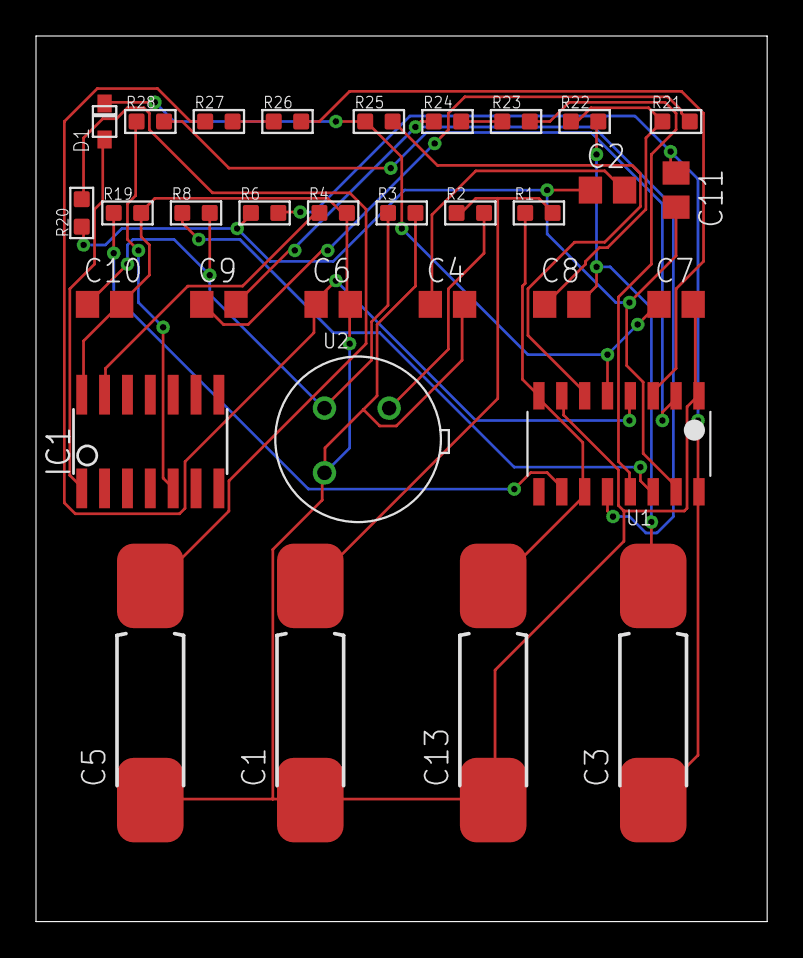
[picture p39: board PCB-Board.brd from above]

Board: 2 copper layers, 40.6 x 49.2 mm, 32 parts (0 on the bottom side), 26 nets.

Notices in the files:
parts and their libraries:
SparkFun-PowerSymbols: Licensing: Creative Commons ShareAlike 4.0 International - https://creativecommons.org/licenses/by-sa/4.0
